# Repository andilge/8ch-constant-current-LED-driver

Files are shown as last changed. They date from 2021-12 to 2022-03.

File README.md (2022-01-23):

# 8 channel LED constant current driver
Constant current driver with esp32 MCU made for esphome

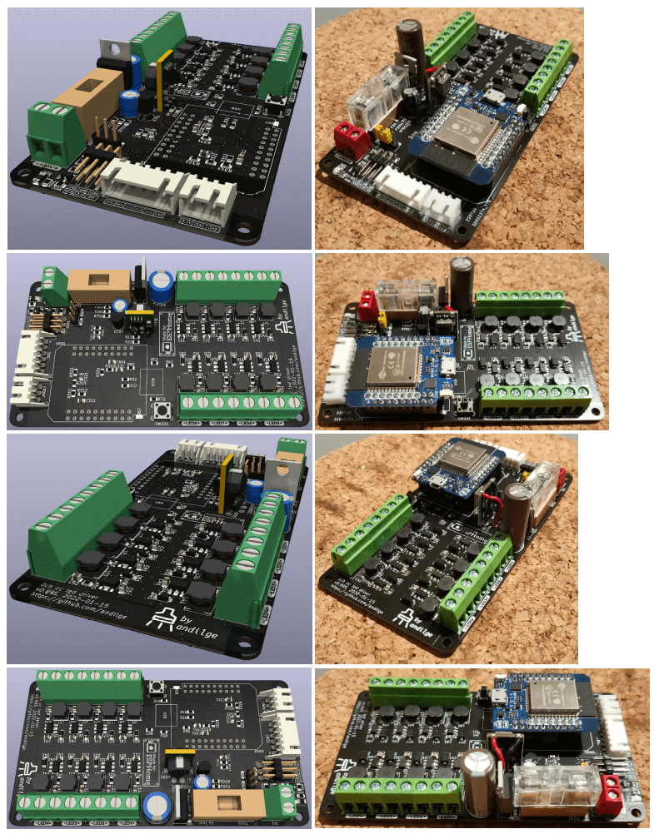
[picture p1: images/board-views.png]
The PCB


## Preamble
We are planning our new house. A seemingly endless process full of technical plans and proposed solutions. Among the proposals there are good ones, bad ones but also too expensive or immature ones.

In the field of automated lighting, the negatives outweigh the good in professional installations. I don’t need sinfully expensive lighting on closed and proprietary systems. Besides, I’ve been using Home Assistant for years and have learned to use ESPHome and want to build up on this.

With this starting position, the desire arose to do all the lighting in the new house myself and to rely on open source. Of course, in 2021 I will be using LED lights and I know that LEDs are best operated with constant current. After discussions with interested experts around the world, I arrived at the module LD24AJTA, which allows DC voltage and dimming with pwm at the input and offers a suitable constant current at the output.

Sweet, I can do nice pwm easily with an ESP32, the first prototype board was soon built up with it. If only all this could be done even faster and easier, without breadboard and soldering connections individually… you know what came next: I built up my own board with the essentials of the module LD24AJTA and an ESP32 on it.

## Where to find things
The board revisions are accessible in the folder "revisions". Check CHANGELOG.md for detailed revision history.

An example esphome yaml file is located in the folder "esphome".

## Controller add-on
Check out [Rotary encoder with a 10 WS2811 F5 LEDs segmented ring on a translucent white blinde plate](https://github.com/andilge/EC11-encoder-with-WS2811-ring "Rotary encoder with a 10 WS2811 F5 LEDs segmented ring on a translucent white blinde plate") as controller add-on for dimming and toggling the lights.

## Where to go
I know some additional information is needed to get going. I'm planning to build up a wiki here with a step by step procedure, but I got no time to roll this off swiftly :-(

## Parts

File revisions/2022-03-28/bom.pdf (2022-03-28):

## Board

Quantity | References | Value | Purchase
8 | C11, C21, C31, C41, C51, C61, C71, C81 | 10uF 50V
8 | C12, C22, C32, C42, C52, C62, C72, C82 | 1uF 50V
3 | C101, C311, C321 | 10nF 25V
1 | C102 | 680uF 50V
1 | C201 | 470uF 10V
3 | C331, C411, C601 | 100nF 50V
8 | D11, D21, D31, D41, D51, D61, D71, D81 | MBR0560
1 | D101 | BZT52C10
1 | D201 | Power LED
1 | F101 | Holder 5.2x20mm
1 | F101 | 4A fast blowing
1 | F201 | 1.1A resettable
1 | F202 | 0.5A resettable | lcsc.com (https://lcsc.com/product-detail/Resettable-Fuses_Brightking-Elec-TAIWAN-SMD0805B050TF_C269104.html)
| IN1, LED1, LED2, LED3, LED4, LED5, LED6,
1 | J301 | JST S6B-XH-A 6in | aliexpress.com
9 | | Screw_Terminal_01x02
1 | J401 | JST S3B-XH-A 3pin
1 | J501 | Pin Header 2x3 horizontal
1 | J801 | Pin Header 1x3 vertical
1 | J801
8 | L11, L21, L31, L41, L51, L61, L71, L81 | 100uH, GLE GCNR6045
1 | Q101 | BR50P06
1 | Q801 | BSS138
8 | *R11, R21, R31, R41, R51, R61, R71, R81 | 0.3Ω +-1%
8 | R12, R22, R32, R42, R52, R62, R72, R82 | 1kΩ
1 | R101 | 82kΩ
1 | R201 | 3.9kΩ
6 | R311, R312, R321, R322 | 10kΩ
2 | R331, R421 | 39kΩ
2 | R332, R422
1 | R701 | 4.7kΩ
1 | R801, R802 | 33Ω
1 | R803 | 33Ω
1 | R804 | 220Ω
1 | SW331 | SW_Push
8 | U11, U21, U31, U41, U51, U61, U71, U81 | PT4115
1 | U201 | step down 5V 3A
1 | U601 | ESP32 mini (CP2104!)
1 | U701 | DS18B20

* Note for R11 – R81

I recommend using +-1% tolerance for constant Iled values over the different channels
With 0.3Ω, it’s 0.1 / 0.3 = 333mA

Smallest recommended resistor is 0.22Ω which will end up in Iled max per channel slightly above 450mA lcsc.com (https://www.lcsc.com/product-detail/Multilayer-Ceramic-Capacitors-MLCC-SMD-SMT_Murata-Electronics-GRM21BR61H106KE43L_C440198.html)
lcsc.com (https://www.lcsc.com/product-detail/Multilayer-Ceramic-Capacitors-MLCC-SMD-SMT_CCTC-TCC0805X7R105M500FT_C376929.html)
lcsc.com (https://www.lcsc.com/product-detail/Multilayer-Ceramic-Capacitors-MLCC-SMD-SMT_Samsung-Electro-Mechanics-CL21B103KAANNNC_C2688117.html)
aliexpress.com
aliexpress.com (https://www.aliexpress.com/item/1005002375358357.html)
lcsc.com (https://lcsc.com/product-detail/Multilayer-Ceramic-Capacitors-MLCC-SMD-SMT_CCTC-TCC0805X7R104K500DT_C282732.html)
lcsc.com (https://www.lcsc.com/product-detail/Schottky-Barrier-Diodes-SBD_Changjiang-Electronics-Tech-CJ-MBR0560_C77338.html)
lcsc.com (https://www.lcsc.com/product-detail/Zener-Diodes_BORN-BZT52C10_C511887.html)
lcsc.com (https://lcsc.com/product-detail/Light-Emitting-Diodes-LED_Orient-ORH-R37A_C400035.html)
lcsc.com (https://www.lcsc.com/product-detail/Fuse-Holders_Xucheng-Elec-C58066_C58066.html)
lcsc.com (https://www.lcsc.com/product-detail/Fuses_Littelfuse-0217004-MXP_C142737.html)
lcsc.com (https://lcsc.com/product-detail/Resettable-Fuses_BHFUSE-BSMD0805-125-6V_C883114.html)
LED7, LED8 | lcsc.com (https://www.lcsc.com/product-detail/Screw-terminal_HIWA-PA001-2P_C128027.html)
| aliexpress.com (https://www.aliexpress.com/item/1005002111262882.html)
| lcsc.com (https://lcsc.com/product-detail/Pin-Headers_BOOMELE-Boom-Precision-Elec-C3410_C3410.html)
| lcsc.com (https://www.lcsc.com/product-detail/Pin-Headers_GEPU-GP26-2520WV-3P_C2681738.html)
Pin Header jumper, long green cap | aliexpress.com (https://www.aliexpress.com/item/1005001568280063.html)
| lcsc.com (https://www.lcsc.com/product-detail/Power-Inductors_GLE-GCNR6045-101MC_C439379.html)
| lcsc.com (https://www.lcsc.com/product-detail/MOSFETs_Foshan-Blue-Rocket-Elec-BR50P06_C358396.html)
| lcsc.com (https://lcsc.com/product-detail/MOSFETs_Yangzhou-Yangjie-Elec-Tech-BSS138_C400505.html)
| lcsc.com (https://lcsc.com/product-detail/Chip-Resistor-Surface-Mount_UNI-ROYAL-Uniroyal-Elec-0805W8F300LT5E_C247157.html)
| lcsc.com (https://www.lcsc.com/product-detail/Chip-Resistor-Surface-Mount_YAGEO-RC0805JR-071KL_C100046.html)
| lcsc.com (https://www.lcsc.com/product-detail/Chip-Resistor-Surface-Mount_YAGEO-AC0805JR-0782KL_C229256.html)
| lcsc.com (https://lcsc.com/product-detail/Chip-Resistor-Surface-Mount_UNI-ROYAL-Uniroyal-Elec-0805W8J0392T5E_C26021.html)
| lcsc.com (https://lcsc.com/product-detail/Chip-Resistor-Surface-Mount_FH-Guangdong-Fenghua-Advanced-Tech-RS-05K103JT_C115295.html)
| lcsc.com (https://lcsc.com/product-detail/Chip-Resistor-Surface-Mount_FH-Guangdong-Fenghua-Advanced-Tech-RS-05K393JT_C294712.html)
6.8kΩ | lcsc.com (https://lcsc.com/product-detail/Chip-Resistor-Surface-Mount_UNI-ROYAL-Uniroyal-Elec-0805W8J0682T5E_C26026.html)
| lcsc.com (https://lcsc.com/product-detail/Chip-Resistor-Surface-Mount_YAGEO-AC0805JR-074K7L_C229219.html)
| lcsc.com
| lcsc.com (https://lcsc.com/product-detail/Chip-Resistor-Surface-Mount_UNI-ROYAL-Uniroyal-Elec-0805W8J0330T5E_C25307.html)
| lcsc.com (https://lcsc.com/product-detail/Chip-Resistor-Surface-Mount_UNI-ROYAL-Uniroyal-Elec-0805W8J0221T5E_C25294.html)
| lcsc.com (https://lcsc.com/product-detail/Tactile-Switches_C-K-PTS645SL43-2LFS_C221874.html)
| lcsc.com (https://www.lcsc.com/product-detail/LED-Drivers_PowTech-CR-PowTech-Shanghai-PT4115B89E_C84512.html)
| aliexpress.com (https://www.aliexpress.com/item/1005003332040548.html)
| aliexpress.com (https://www.aliexpress.com/item/33043305592.html)
| lcsc.com (https://www.lcsc.com/product-detail/Temperature-Sensors_UMW-Youtai-Semiconductor-Co-Ltd-DS18B20_C376006.html)

The board can handle up to 500mA per channel. Changing the resistor has impact on Iled max which is calculated 0.1 / R.

You can throttle the power in esphome yaml code to meet your light's characteristic

## Installation

### Materials

Quantity | Reference | Value | Purchase
1 | Power supply | 24V/100W
1 | Enclosure box | 150x100x50mm
4 | M3x5 screw | M3x6
4 | M3 washer | M3x6x0.8
9 | DC sockets | DC-022B
9 | DC plugs | DC-022B
100m | DC cable | 20AWG
1 | | EC11
1 | Encoder knob | Marshall white
1 | Blank cover panel
1 | Motion detection sensor | AM312

### Tools

Quantity | Reference | Value | Purchase
1 | Crimping plier JST XH | SN-2549
1 | 3 ceramic tweezers | aliexpress.com (https://www.aliexpress.com/item/32872002684.html)
| Ferrules + Terminal
5m | Transparent heat shrink tube 3:1 | aliexpress.com (https://www.aliexpress.com/item/32707478629.html)
| SMD soldering heating
1 | 6" diagonal wire cutter nipper | aliexpress.com (https://www.aliexpress.com/item/1005003653231158.html)
| WAGO connectors combo
100g | Solder wire 0.6mm | aliexpress.com (https://www.aliexpress.com/item/1005002788585134.html)
1 | HSC8 6-6
1 | MECHANIC ET-10

1

1 | Soldering paste 138°C
1 | Extra Flux | | aliexpress.com (https://www.aliexpress.com/item/1005002680913932.html)
| Desoldering wick 2mm x
1 | Multimeter | ZT301 | aliexpress.com (https://www.aliexpress.com/item/32887493467.html)

1x10

aliexpress.com (https://www.aliexpress.com/item/4000834576979.html)
aliexpress.com (https://www.aliexpress.com/item/1005001861093267.html)
aliexpress.com (https://www.aliexpress.com/item/1005002306042593.html)
aliexpress.com (https://www.aliexpress.com/item/1005002439751580.html)
aliexpress.com (https://www.aliexpress.com/item/32923781995.html)
aliexpress.com (https://www.aliexpress.com/item/32897664061.html)
aliexpress.com (https://www.aliexpress.com/item/1005003474533191.html)
Rotary encoder 15mm
plum handle | aliexpress.com (https://www.aliexpress.com/item/1005002048077280.html)
| aliexpress.com (https://www.aliexpress.com/item/1005002362022710.html)
| aliexpress.com (https://www.aliexpress.com/item/32884601740.html)
| aliexpress.com (https://www.aliexpress.com/item/32988314171.html)

aliexpress.com (https://www.aliexpress.com/item/4000331316447.html)

Crimping Plier | aliexpress.com (https://www.aliexpress.com/item/32831768783.html?)
plate | aliexpress.com (https://www.aliexpress.com/item/1005001705260291.html)
kit | aliexpress.com (https://www.aliexpress.com/item/32371475690.html)
| aliexpress.com (https://www.aliexpress.com/item/1005002799325191.html)
1.5m | aliexpress.com (https://www.aliexpress.com/item/32931554391.html)

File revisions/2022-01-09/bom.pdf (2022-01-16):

## Board

Quantity | References | Value | Purchase
11 | | 100nF 50V
8 | C12, C22, C32, C42, C52, C62, C72, C82 | 1uF 50V
3 | C101, C311, C321 | 10nF 25V
1 | C102 | 470uF 50V
1 | C201 | 220uF 10V | lcsc.com (https://lcsc.com/product-detail/Aluminum-Electrolytic-Capacitors-Leaded_Capxon-International-Elec-KF221M010E070A_C59330.html)
| C331, C421, C601 | 100nF 50V
8 | D11, D21, D31, D41, D51, D61, D71, D81 | MBR0560 | lcsc.com (https://www.lcsc.com/product-detail/Schottky-Barrier-Diodes-SBD_Changjiang-Electronics-Tech-CJ-MBR0560_C77338.html)
1 | D101 | BZT52C10
1 | D201 | Pow LED
1 | F101 | Holder 5.2x20mm
1 | F101 | 4A fast blowing
1 | F201 | 1A resettable
9 | | Screw_Terminal_01x02
1 | J301 | S4B-XH-A
1 | J401 | S3B-XH-A
1 | J501 | Conn_02x04_Male
8 | L11, L21, L31, L41, L51, L61, L71, L81 | 100uH, GLE GCNR6045
1 | Q101 | BR50P06
8 | *R11, R21, R31, R41, R51, R61, R71, R81 | 0.3Ω +-1%
8 | R12, R22, R32, R42, R52, R62, R72, R82 | 1kΩ
1 | R101 | 82kΩ
1 | R201 | 3.9kΩ
4 | R311, R312, R321, R322 | 10kΩ
2 | R331, R421 | 39kΩ
2 | R332, R422
1 | R701 | 4.7kΩ
8 | U11, U21, U31, U41, U51, U61, U71, U81 | PT4115
1 | U201 | step down 5V 1A
1 | U601 | ESP32 mini (CP2104!)
1 | U701 | DS18B20

* Note for R11 – R81

I recommend using +-1% tolerance for constant Iled values over the different channels
With 0.3Ω, it’s 0.1 / 0.3 = 333mA

Smallest recommended resistor is 0.22Ω which will end up in Iled max per channel slightly above 450mA

C11, C21, C31, C41, C51, C61, C71, C81, C331, C421,
C601 | lcsc.com (https://www.lcsc.com/product-detail/Multilayer-Ceramic-Capacitors-MLCC-SMD-SMT_Murata-Electronics-GRM21BR61H106KE43L_C440198.html)
| lcsc.com (https://www.lcsc.com/product-detail/Multilayer-Ceramic-Capacitors-MLCC-SMD-SMT_CCTC-TCC0805X7R105M500FT_C376929.html)
| lcsc.com (https://www.lcsc.com/product-detail/Multilayer-Ceramic-Capacitors-MLCC-SMD-SMT_Samsung-Electro-Mechanics-CL21B103KAANNNC_C2688117.html)
| lcsc.com (https://www.lcsc.com/product-detail/Aluminum-Electrolytic-Capacitors-Leaded_KNSCHA-01EC4236_C2760863.html)
| lcsc.com (https://lcsc.com/product-detail/Multilayer-Ceramic-Capacitors-MLCC-SMD-SMT_CCTC-TCC0805X7R104K500DT_C282732.html)
| lcsc.com (https://www.lcsc.com/product-detail/Zener-Diodes_Shandong-Jingdao-Microelectronics-BZT52C10_C353564.html)
| lcsc.com (https://lcsc.com/product-detail/Light-Emitting-Diodes-LED_Orient-ORH-R37A_C400035.html)
| lcsc.com (https://www.lcsc.com/product-detail/Fuse-Holders_Xucheng-Elec-C58066_C58066.html)
| lcsc.com (https://www.lcsc.com/product-detail/Fuses_Littelfuse-0217004-MXP_C142737.html)
| lcsc.com (https://lcsc.com/product-detail/Resettable-Fuses_BHFUSE-BSMD0805-100-12V_C910823.html)
IN1, LED1, LED2, LED3, LED4, LED5, LED6, LED7,
LED8 | lcsc.com (https://www.lcsc.com/product-detail/Screw-terminal_HIWA-PA001-2P_C128027.html)
| lcsc.com (https://lcsc.com/product-detail/Wire-To-Board-Wire-To-Wire-Connector_BOOMELE-Boom-Precision-Elec-XH-4AW_C21273.html)
| lcsc.com (https://lcsc.com/product-detail/Wire-To-Board-Wire-To-Wire-Connector_BOOMELE-Boom-Precision-Elec-XH-3AW_C18428.html)
| lcsc.com (https://lcsc.com/product-detail/Pin-Headers_BOOMELE-Boom-Precision-Elec-C3410_C3410.html)
| lcsc.com (https://www.lcsc.com/product-detail/Power-Inductors_GLE-GCNR6045-101MC_C439379.html)
| lcsc.com (https://www.lcsc.com/product-detail/MOSFETs_Foshan-Blue-Rocket-Elec-BR50P06_C358396.html)
| lcsc.com (https://lcsc.com/product-detail/Chip-Resistor-Surface-Mount_UNI-ROYAL-Uniroyal-Elec-0805W8F300LT5E_C247157.html)
| lcsc.com (https://www.lcsc.com/product-detail/Chip-Resistor-Surface-Mount_YAGEO-RC0805JR-071KL_C100046.html)
| lcsc.com (https://www.lcsc.com/product-detail/Chip-Resistor-Surface-Mount_YAGEO-AC0805JR-0782KL_C229256.html)
| lcsc.com (https://lcsc.com/product-detail/Chip-Resistor-Surface-Mount_UNI-ROYAL-Uniroyal-Elec-0805W8J0392T5E_C26021.html)
| lcsc.com (https://lcsc.com/product-detail/Chip-Resistor-Surface-Mount_FH-Guangdong-Fenghua-Advanced-Tech-RS-05K103JT_C115295.html)
| lcsc.com (https://lcsc.com/product-detail/Chip-Resistor-Surface-Mount_FH-Guangdong-Fenghua-Advanced-Tech-RS-05K393JT_C294712.html)
6.8kΩ | lcsc.com (https://lcsc.com/product-detail/Chip-Resistor-Surface-Mount_UNI-ROYAL-Uniroyal-Elec-0805W8J0682T5E_C26026.html)
| lcsc.com (https://lcsc.com/product-detail/Chip-Resistor-Surface-Mount_YAGEO-AC0805JR-074K7L_C229219.html)
| lcsc.com (https://www.lcsc.com/product-detail/LED-Drivers_PowTech-CR-PowTech-Shanghai-PT4115B89E_C84512.html)
| aliexpress.com (https://www.aliexpress.com/item/1005001910573870.html)
| aliexpress.com (https://www.aliexpress.com/item/33043305592.html)
| lcsc.com (https://www.lcsc.com/product-detail/Temperature-Sensors_UMW-Youtai-Semiconductor-Co-Ltd-DS18B20_C376006.html)

The board can handle up to 500mA per channel. Changing the resistor has impact on Iled max which is calculated 0.1 / R.

You can throttle the power in esphome yaml code to meet your light's characteristic

## Installation

### Materials

Quantity | Reference | Value | Purchase
1 | Power supply | 24V/100W
1 | Enclosure box | 150x100x50mm
4 | M3x5 screw | M3x6
4 | M3 washer | M3x6x0.8
9 | DC sockets | DC-022B
9 | DC plugs | DC-022B
100m | DC cable | 20AWG
1 | Rotary encoder | EC11
1 | Encoder knob | Marshall white
1 | Blank cover panel
1 | Motion detection sensor | AM312

### Tools

Quantity | Reference | Value | Purchase
1 | Crimping plier JST XH | SN-2549

aliexpress.com (https://www.aliexpress.com/item/4000834576979.html)
aliexpress.com (https://www.aliexpress.com/item/1005001861093267.html)
aliexpress.com (https://www.aliexpress.com/item/1005002306042593.html)
aliexpress.com (https://www.aliexpress.com/item/1005002439751580.html)
aliexpress.com (https://www.aliexpress.com/item/32923781995.html)
aliexpress.com (https://www.aliexpress.com/item/32897664061.html)
aliexpress.com (https://www.aliexpress.com/item/1005003474533191.html)
aliexpress.com (https://www.aliexpress.com/item/1005002048077280.html)
aliexpress.com (https://www.aliexpress.com/item/1005002362022710.html)
aliexpress.com (https://www.aliexpress.com/item/32884601740.html)
aliexpress.com (https://www.aliexpress.com/item/32988314171.html)

aliexpress.com (https://www.aliexpress.com/item/4000331316447.html)

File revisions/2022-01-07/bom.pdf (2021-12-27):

## Board

Quantity | References | Value | Purchase
11 | | 100nF 50V
8 | C12, C22, C32, C42, C52, C62, C72, C82 | 1uF 50V
3 | C101, C311, C321 | 10nF 25V
1 | C102 | 470uF 50V
1 | C201 | 220uF 10V
8 | D11, D21, D31, D41, D51, D61, D71, D81 | MBR0560
1 | D101 | BZT52C10
1 | D201 | Pow LED
1 | F101 | Holder 5.2x20mm
1 | F101 | 4A fast blowing
1 | F201 | 1A resettable | lcsc.com (https://lcsc.com/product-detail/Resettable-Fuses_BHFUSE-BSMD0805-100-12V_C910823.html)
| IN1, LED1, LED2, LED3, LED4, LED5, LED6, LED7,
1 | J301 | S4B-XH-A | lcsc.com (https://lcsc.com/product-detail/Wire-To-Board-Wire-To-Wire-Connector_JST-Sales-America-S4B-XH-A-LF-SN_C157925.html)
9 | | Screw_Terminal_01x02
1 | J401 | S3B-XH-A
1 | J501 | Conn_02x04_Male
8 | L11, L21, L31, L41, L51, L61, L71, L81 | 100uH, GLE GCNR6045
1 | Q101 | BR50P06
8 | *R11, R21, R31, R41, R51, R61, R71, R81 | 0.36Ω +-1%
1 | R101 | 82kΩ
1 | R201 | 3.9kΩ
4 | R311, R312, R321, R322 | 10kΩ
2 | R332, R422
2 | R331, R421 | 39kΩ
1 | R701 | 4.7kΩ
8 | U11, U21, U31, U41, U51, U61, U71, U81 | PT4115
1 | U201 | step down 5V 1A
1 | U601 | ESP32 mini (CP2104!)
1 | U701 | DS18B20

* Note for R11 – R81

With 0.36Ω, it’s 0.1 / 0.36 = 278mA (measured 290mA)
I recommend using +-1% tolerance for constant Iled values over the different channels
Smallest recommended resistor is 0.22Ω which will end up in Iled max per channel little more than 450mA

C11, C21, C31, C41, C51, C61, C71, C81, C331, C421,
C601 | lcsc.com (https://lcsc.com/product-detail/Multilayer-Ceramic-Capacitors-MLCC-SMD-SMT_CCTC-TCC0805X7R104K500DT_C282732.html)
| lcsc.com (https://www.lcsc.com/product-detail/Multilayer-Ceramic-Capacitors-MLCC-SMD-SMT_CCTC-TCC0805X7R105M500FT_C376929.html)
| lcsc.com (https://lcsc.com/product-detail/Multilayer-Ceramic-Capacitors-MLCC-SMD-SMT_Samsung-Electro-Mechanics-CL21B103KAANNNC_C2688117.html)
| lcsc.com (https://www.lcsc.com/product-detail/Aluminum-Electrolytic-Capacitors-Leaded_KNSCHA-01EC4236_C2760863.html)
| lcsc.com (https://www.lcsc.com/product-detail/Aluminum-Electrolytic-Capacitors-Leaded_Capxon-International-Elec-KF221M010E070A_C59330.html)
| lcsc.com (https://www.lcsc.com/product-detail/Schottky-Barrier-Diodes-SBD_Changjiang-Electronics-Tech-CJ-MBR0560_C77338.html)
| lcsc.com (https://www.lcsc.com/product-detail/Zener-Diodes_GOODWORK-BZT52C10_C2903914.html)
| lcsc.com (https://www.lcsc.com/product-detail/Light-Emitting-Diodes-LED_Lite-On-LTST-C150KFKT_C284937.html)
| lcsc.com (https://www.lcsc.com/product-detail/Fuse-Holders_Xucheng-Elec-C58066_C58066.html)
| lcsc.com (https://www.lcsc.com/product-detail/Fuses_Walter-Elec-FSD5A250V_C357863.html)
LED8 | lcsc.com (https://lcsc.com/product-detail/Screw-terminal_HIWA-PA001-2P_C128027.html)
| lcsc.com (https://lcsc.com/product-detail/Wire-To-Board-Wire-To-Wire-Connector_JST-Sales-America-S3B-XH-A-LF-SN_C157928.html)
| lcsc.com (https://lcsc.com/product-detail/Pin-Headers_BOOMELE-Boom-Precision-Elec-C3410_C3410.html)
| lcsc.com (https://lcsc.com/product-detail/Power-Inductors_GLE-GCNR6045-101MC_C439379.html)
| lcsc.com (https://www.lcsc.com/product-detail/MOSFETs_Foshan-Blue-Rocket-Elec-BR50P06_C358396.html)
| lcsc.com (https://lcsc.com/product-detail/Chip-Resistor-Surface-Mount_Milliohm-HoLTT0805-1-8W-360mR-1_C2904550.html)
| lcsc.com (https://www.lcsc.com/product-detail/Chip-Resistor-Surface-Mount_FH-Guangdong-Fenghua-Advanced-Tech-RS-05K823JT_C294742.html)
| lcsc.com (https://www.lcsc.com/product-detail/Chip-Resistor-Surface-Mount_UNI-ROYAL-Uniroyal-Elec-0805W8J0332T5E_C26020.html)
| lcsc.com (https://lcsc.com/product-detail/Chip-Resistor-Surface-Mount_FH-Guangdong-Fenghua-Advanced-Tech-RS-05K103JT_C115295.html)
6.8kΩ | lcsc.com (https://lcsc.com/product-detail/Pin-Headers_BOOMELE-Boom-Precision-Elec-C3410_C3410.html)
| lcsc.com (https://lcsc.com/product-detail/Chip-Resistor-Surface-Mount_FH-Guangdong-Fenghua-Advanced-Tech-RS-05K393JT_C294712.html)
| lcsc.com (https://www.lcsc.com/product-detail/Chip-Resistor-Surface-Mount_FOJAN-FRC0805J472-TS_C2907326.html)
| lcsc.com (https://www.lcsc.com/product-detail/LED-Drivers_PowTech-CR-PowTech-Shanghai-PT4115B89E_C84512.html)
| aliexpress.com (https://www.aliexpress.com/item/4000549890103.html)
| aliexpress.com (https://www.aliexpress.com/item/32858054775.html)
| lcsc.com (https://www.lcsc.com/product-detail/Temperature-Sensors_UMW-Youtai-Semiconductor-Co-Ltd-DS18B20_C376006.html)

The board can handle up to 500mA per channel. Changing the resistor has impact on Iled max which is calculated 0.1 / R.

## Installation

Quantity | Reference | Value | Purchase
1 | Power supply | 24V/100W
1 | Enclosure box | 150x100x50mm
4 | M3x5 screw | M3x6
4 | M3 washer | M3x6x0.8
9 | DC sockets | DC-022B
9 | DC plugs | DC-022B
100m | DC cable | 20AWG
1 | Rotary encoder | EC11
1 | Blank cover panel
1 | Encoder knob
1 | Motion detection sensor | AM312
1 | Crimping plier JST XH | SN-2549

aliexpress.com (https://www.aliexpress.com/item/4000834576979.html)
aliexpress.com (https://www.aliexpress.com/item/1005001861093267.html)
aliexpress.com (https://www.aliexpress.com/item/1005002306042593.html)
aliexpress.com (https://www.aliexpress.com/item/1005002439751580.html)
aliexpress.com (https://www.aliexpress.com/item/32923781995.html)
aliexpress.com (https://www.aliexpress.com/item/32897664061.html)
aliexpress.com (https://www.aliexpress.com/item/1005003474533191.html)
aliexpress.com (https://www.aliexpress.com/item/1005002048077280.html)
aliexpress.com (https://www.aliexpress.com/item/32884601740.html)
aliexpress.com (https://www.aliexpress.com/item/1005002362022710.html)
aliexpress.com (https://www.aliexpress.com/item/32988314171.html)
aliexpress.com (https://www.aliexpress.com/item/4000331316447.html)

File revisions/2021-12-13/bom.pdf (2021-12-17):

## Board

Quantity | References | Value | Purchase
9 | C11, C21, C31, C41, C51, C61, C71, C81, C201 | 100nF 50V
8 | C12, C22, C32, C42, C52, C62, C72, C82 | 1uF 50V
1 | C100 | 10nF 25V
1 | C101 | 470uF 50V
1 | C200 | 220uF 10V
8 | *R1, R2, R3, R4, R5, R6, R7, R8 | 0R36 +-1%
1 | R20 | 4k7
1 | R100 | 82k
1 | R200 | 3k3 | lcsc.com (https://www.lcsc.com/product-detail/Chip-Resistor-Surface-Mount_UNI-ROYAL-Uniroyal-Elec-0805W8J0332T5E_C26020.html)
| | 100uH, GLE GCNR6045-
8 | D1, D2, D3, D4, D5, D6, D7, D8 | MBR0560 | lcsc.com (https://www.lcsc.com/product-detail/Schottky-Barrier-Diodes-SBD_Changjiang-Electronics-Tech-CJ-MBR0560_C77338.html)
8 | L1, L2, L3, L4, L5, L6, L7, L8
1 | D100 | BZT52C10
1 | D200 | Pow LED
8 | U1, U2, U3, U4, U5, U6, U7, U8 | PT4115
1 | U10 | ESP32 mini (CP2104 drive)
1 | U20 | DS18B20
1 | U200 | step down 5V 1A
1 | F100 | Holder 5.2x20mm
| | 5A fast blowing
1 | F200 | 1A
9 | | Screw_Terminal_01x02
1 | Q100 | BR50P06
1 | J110 | Conn_01x06_Male
1 | J120 | Conn_01x03_Male
1 | J130 | Conn_01x04_Male

* Note for R1 – R8

With 0.36Ω, it’s 0.1 / 0.36 = 278mA (measured 290mA)
I recommend using +-1% tolerance for constant Iled values over the different channels
Smallest recommended resistor is 0.22Ω which will end up in Iled max per channel little more than 450mA lcsc.com (https://www.lcsc.com/product-detail/Multilayer-Ceramic-Capacitors-MLCC-SMD-SMT_CCTC-TCC0805X7R104K500DT_C282732.html)
lcsc.com (https://www.lcsc.com/product-detail/Multilayer-Ceramic-Capacitors-MLCC-SMD-SMT_CCTC-TCC0805X7R105M500FT_C376929.html)
lcsc.com (https://www.lcsc.com/product-detail/Multilayer-Ceramic-Capacitors-MLCC-SMD-SMT_YAGEO-CC0805KRX7R8BB103_C519911.html)
lcsc.com (https://www.lcsc.com/product-detail/Aluminum-Electrolytic-Capacitors-Leaded_KNSCHA-01EC4236_C2760863.html)
lcsc.com (https://www.lcsc.com/product-detail/Aluminum-Electrolytic-Capacitors-Leaded_Capxon-International-Elec-KF221M010E070A_C59330.html)
lcsc.com (https://www.lcsc.com/product-detail/Chip-Resistor-Surface-Mount_UNI-ROYAL-Uniroyal-Elec-0805W8F360LT5E_C35793.html)
lcsc.com (https://www.lcsc.com/product-detail/Chip-Resistor-Surface-Mount_FOJAN-FRC0805J472-TS_C2907326.html)
lcsc.com (https://www.lcsc.com/product-detail/Chip-Resistor-Surface-Mount_FH-Guangdong-Fenghua-Advanced-Tech-RS-05K823JT_C294742.html)
101MC | lcsc.com (https://www.lcsc.com/product-detail/Power-Inductors_GLE-GCNR6045-101MC_C439379.html)
| lcsc.com (https://www.lcsc.com/product-detail/Zener-Diodes_GOODWORK-BZT52C10_C2903914.html)
| lcsc.com (https://www.lcsc.com/product-detail/Light-Emitting-Diodes-LED_Lite-On-LTST-C150KFKT_C284937.html)
| lcsc.com (https://www.lcsc.com/product-detail/LED-Drivers_PowTech-CR-PowTech-Shanghai-PT4115B89E_C84512.html)
| aliexpress.com (https://www.aliexpress.com/item/33043305592.html)
| lcsc.com (https://www.lcsc.com/product-detail/Temperature-Sensors_UMW-Youtai-Semiconductor-Co-Ltd-DS18B20_C376006.html)
| aliexpress.com (https://www.aliexpress.com/item/1005001910573870.html)
| lcsc.com (https://www.lcsc.com/product-detail/Fuse-Holders_Xucheng-Elec-C58066_C58066.html)
| lcsc.com (https://www.lcsc.com/product-detail/Fuses_Walter-Elec-FSD5A250V_C357863.html)
| lcsc.com (https://www.lcsc.com/product-detail/Resettable-Fuses_Jinrui-Electronic-Materials-Co-JK-SMD0805-100-6V_C2830233.html)
IN1, LED1, LED2, LED3, LED4, LED5, LED6, LED7,
LED8 | lcsc.com (https://www.lcsc.com/product-detail/Screw-terminal_Cixi-Kefa-Elec-KF301-5-0-2P_C474881.html)
| lcsc.com (https://www.lcsc.com/product-detail/MOSFETs_Foshan-Blue-Rocket-Elec-BR50P06_C358396.html)
| aliexpress.com (https://www.aliexpress.com/item/33043163402.html)
| aliexpress.com (https://www.aliexpress.com/item/4000029752340.html)
| aliexpress.com (https://www.aliexpress.com/item/4000029721517.html)

The board can handle up to 500mA per channel. Changing the resistor has impact on Iled max which is calculated 0.1 / R.

## Installation

Quantity | Reference | Value | Purchase
1 | Power supply | 24V/100W
1 | Enclosure box | 150x100x50mm
4 | M3x5 screw | M3x6
4 | M3 washer | M3x6x0.8
9 | DC sockets | DC-022B
9 | DC plugs | DC-022B
100m | DC cable | 20AWG
1 | Rotary encoder | EC11
1 | Blank cover panel
1 | Encoder knob
1 | Motion detection sensor | AM312
1 | Crimping plier JST XH | SN-2549

aliexpress.com (https://www.aliexpress.com/item/4000834576979.html)
aliexpress.com (https://www.aliexpress.com/item/1005001861093267.html)
aliexpress.com (https://www.aliexpress.com/item/1005002306042593.html)
aliexpress.com (https://www.aliexpress.com/item/1005002439751580.html)
aliexpress.com (https://www.aliexpress.com/item/32923781995.html)
aliexpress.com (https://www.aliexpress.com/item/32897664061.html)
aliexpress.com (https://www.aliexpress.com/item/1005003474533191.html)
aliexpress.com (https://www.aliexpress.com/item/1005002048077280.html)
aliexpress.com (https://www.aliexpress.com/item/32884601740.html)
aliexpress.com (https://www.aliexpress.com/item/1005002362022710.html)
aliexpress.com (https://www.aliexpress.com/item/32988314171.html)
aliexpress.com (https://www.aliexpress.com/item/4000331316447.html)

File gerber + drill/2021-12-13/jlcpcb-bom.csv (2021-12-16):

Comment | Designator | Footprint | LCSC
10nF | C100 | Capacitor_SMD:C_0805_2012Metric | C2688117
470uF | C101 | Capacitor_THT:CP_Radial_D10.0mm_P5.00mm | C2760863
100nF | C10,C11,C21,C31,C41,C51,C61,C71,C81 | Capacitor_SMD:C_0805_2012Metric | C282732
1uF | C12,C22,C32,C42,C52,C62,C72,C82 | Capacitor_SMD:C_0805_2012Metric | C376929
220uF | C200 | Capacitor_THT:CP_Radial_D6.3mm_P2.50mm | C59330
BZT52C10 | D100 | Diode_SMD:D_SOD-323 | C353564
Pow LED | D200 | Diode_SMD:D_1206_3216Metric | C130716
MBR0560 | D1,D2,D3,D4,D5,D6,D7,D8 | Diode_SMD:D_SOD-123 | C77338
5A fast | F100 | Fuse:Fuseholder_Cylinder-5x20mm_Stelvio-Kontek_PTF78_Horizontal_Open | C58066
1A | F200 | Resistor_SMD:R_0805_2012Metric | C369152
Screw_Terminal_01x02 | IN1,LED1,LED2,LED3,LED4,LED5,LED6,LED7,LED8 | TerminalBlock_MetzConnect:TerminalBlock_MetzConnect_Type101_RT01602HBWC_1x02_P5.08mm_Horizontal | C474881
Conn_01x06_Male | J110 | Connector_PinHeader_2.54mm:PinHeader_2x03_P2.54mm_Horizontal | C492431
Conn_01x03_Male | J120 | Connector_JST:JST_EH_S3B-EH_1x03_P2.50mm_Horizontal | C144402
Conn_01x04_Male | J130 | Connector_JST:JST_EH_S4B-EH_1x04_P2.50mm_Horizontal | C144403
100uH | L1,L2,L3,L4,L5,L6,L7,L8 | Inductor_SMD:L_Bourns_SRN6045TA | C439379
BR50P06 | Q100 | Package_TO_SOT_THT:TO-220-3_Vertical | C358396
82k | R100 | Resistor_SMD:R_0805_2012Metric | C229256
4k7 | R20 | Resistor_SMD:R_0805_2012Metric | C229219
3k3 | R200 | Resistor_SMD:R_0805_2012Metric | C26020
0R36 | R1,R2,R3,R4,R5,R6,R7,R8 | Resistor_SMD:R_0805_2012Metric | C35793
PT4115 | U1,U2,U3,U4,U5,U6,U7,U8 | Package_TO_SOT_SMD:SOT-89-5 | C84512
DS18B20 | U20 | Package_TO_SOT_THT:TO-92_Inline | C376006

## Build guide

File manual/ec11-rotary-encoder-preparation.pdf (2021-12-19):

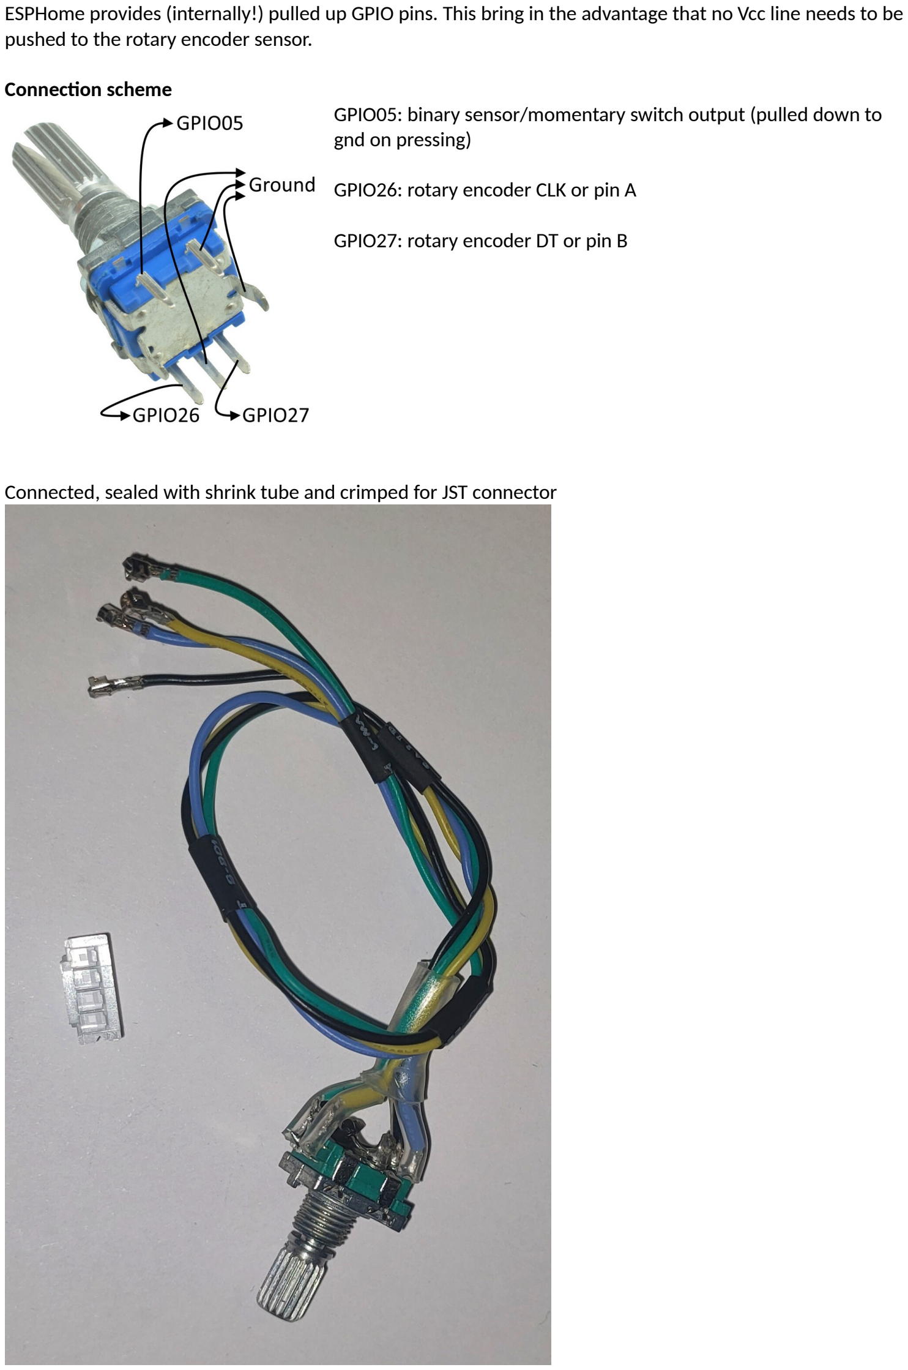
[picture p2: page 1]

ESPHome provides (internally!) pulled up GPIO pins. This bring in the advantage that no Vcc line needs to be pushed to the rotary encoder sensor.

Connection scheme
GPIO05: binary sensor/momentary switch output (pulled down to gnd on pressing)

GPIO26: rotary encoder CLK or pin A

GPIO27: rotary encoder DT or pin B

Connected, sealed with shrink tube and crimped for JST connector

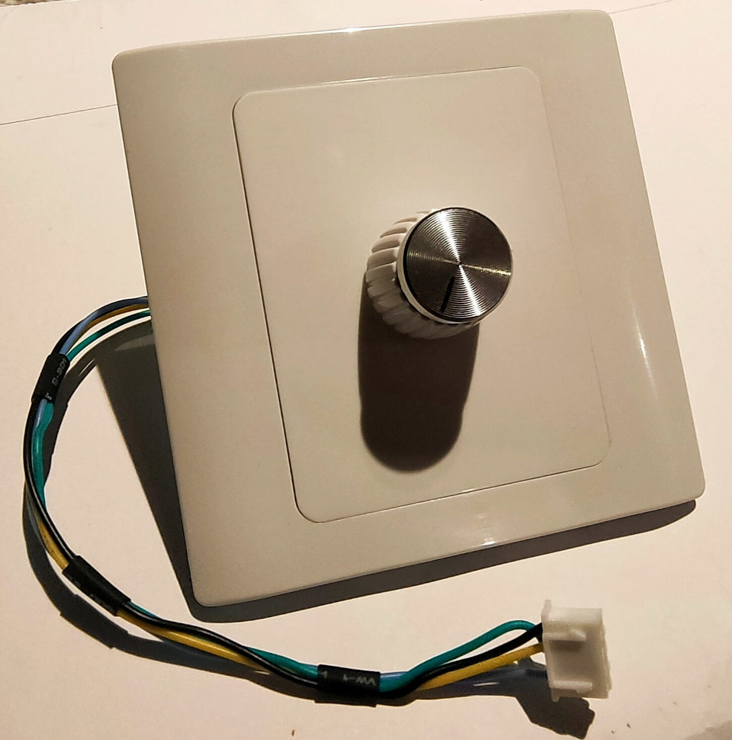
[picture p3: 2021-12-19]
manual/ec11-rotary-encoder-final.jpg

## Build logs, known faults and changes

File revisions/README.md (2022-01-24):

# Each folder stands for it's own revision showing the build date

## folder board-views
Here some preview pictures of the board. What you see is what you'll get in the end.

## folder jlcpcb-board-fabrication
### jlcpcb-gerber-drill-map.zip
The zip file is adapted to the manufacturers needs and contains it all. No need to unpack, it can be uploaded to the board manufacturer as it is. All tests with the board passed QC with 1oz copper layers.

### smt-bom.csv and smt-top-pos.csv
These 2 files can be used if you want jlcpcb.com to solder all SMD components on the board. Please upload smt-bom.csv as BOM, smt-top-pos.csv as CPL.
**ATTENTION**: All through hole components are *NOT* included in this BOM and the pre-assembly process. Please complete the board by manualy soldering them!

## folder pcbway-board-fabrication
### pcbway-gerber-drill-map.zip
The zip file is adapted to the manufacturers needs and contains it all. No need to unpack, it can be uploaded to the board manufacturer as it is. All tests with the board passed QC with 1oz copper layers.

## bom.pdf
This is the list with all parts and some installation material. *Download* the file and get access to real offers in the column "purchase" (suggestive).

## ibom.html
This is the interactive bill of materials which will help you placing the components on the board. It also shows more information about the components' footprint designators.

Here some [usage hints](https://github.com/openscopeproject/InteractiveHtmlBom/wiki/Usage#bom-page-mouse-actions).

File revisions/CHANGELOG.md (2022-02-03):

# Changelog

## [Unreleased]
### To be added
- Bigger 5V buck converter to serve additional power consumption of the addressbale LEDs
- Deep diving once again into tests with infrared thermal cam on the very last revision. Don't get me wrong, this has been done with positive results in earlier revisions and it's only been improved. Documentation and publication is lacking though
- Wiki and step by step guide. I know I'm lazy at documentation, just more fascinated in getting things up, running and QCed :-)
- Tests with all the external sensor/actor stuff with pir motion sensor and rotary encoder on 10 meter distant from board. Since the connectors have changed with v0.99 and debouncing/hum filter has dropped in with v0.991 I'll have to wait until these parts and the new board version are here first

## [0.996] - 2022-02-03
### Added
### Changed
- better zone handling around the mounting holes
- wider radius on many rounded corners for trackes, better track fillets
- better placement on some debouncing filter components, shortening tracks
- some minor cosmetics all around the board
### Deprecated
### Removed
### Fixed
### Security

## [0.995] - 2022-01-15
### Added
- Introducing a data bus for adressable LEDs on 6 pin JST XH connector going to encoder
- Simple level shifter 3.3V to 5V for data line
- Selectable data line attenuation 33Ω (short cable) or 253Ω (long cable) with pin header jumper
- Addtitional resettable fuse for LED power line
### Changed
- new buck converter delivering more power for the adressable LEDs on the controller
- new placment for power supply, debouncing filter and connector components
- rerouting all tracks on these components
### Deprecated
### Removed
### Fixed
### Security

## [0.994] - 2022-01-07
### Added
- Adding push button on the board (parallel to the one in the rotary encoder)
### Changed
- Fillet tracks for all tracks
- Minor routing improvments all over the board
### Deprecated
### Removed
### Fixed
- Eliminating some courtyard overlap errors by slightly changing component placements
- Adding decoupling resistors in PWM lines
### Security

## [0.993] - 2022-01-07
### Added
- Introducing fillet tracks (rounded corner in tracks)
### Changed
- Moving the light power components to the board's edge => larger power zone in the middle, lowering resistance
- Redoing all the zones, reconnecting some tracks
- Revamping the buzzard labels near the screw terminals
### Deprecated
### Removed
### Fixed
### Security

## [0.992] - 2022-01-05
### Added
- Introducing small buzzard labels near the screw terminals
- Introducing thermal reliefs on though hole and smd solder pads when in a zone
### Changed
- minor changes of placement of some vias, moving away from silk screens
### Deprecated
### Removed
### Fixed
### Security

## [0.99r2] - 2021-12-16
### Added
- introducing jlcpcb-smd-bom.csv BOM and jlcpcb-top-pos.csv CPL for the SMD assembly of the board by jlcpcb. **ATTENTION**: All through hole components are NOT included in this per-assembly process. Please complete the board by manually soldering them
### Changed
### Deprecated
### Removed
### Fixed
### Security

## [0.99] - 2021-12-13
### Added
### Changed
- using horizontal JST connectors near the board edge to enable connecting the pir sensor and rotary encoder easily thru the enclosure
- new placement for the esp32 giving space for the JST connectors near the board edge
- rerouting all tracks around the JST connectors and esp32
- minor improvments in the 5 Volt line, better componenent placement and track routing
### Deprecated
### Removed
### Fixed
### Security

## [0.98] - 2021-12-12
### Added
### Changed
- new power inductor Bourns SRN6045 for better availabilty (widley spread in different stocks).
- Alternative inductor is GLE GCNR6045 with same characteristics and dimensions
- spreading out ground area on front and back layer
- silkscreen near screw terminal connectors LED1 - LED4 rotated for better readability
- new graphics for board dimensions and mounting hole distances
### Deprecated
### Removed
### Fixed
### Security

## [0.97] - 2021-12-10
### Added
- introducing CHANGELOG.md with format based on [Keep a Changelog](https://keepachangelog.com)
### Changed
- optimizing vias
- small improvement on vcc tracks to led driver ic
- other minor enhancements and improvements
### Deprecated
### Removed
### Fixed
### Security

## [0.96] - 2021-12-07
### Added
### Changed
- better silkscreens at screw terminal connectors
- thicker and better tracks to the LED outputs
- other minor enhancements and improvements
### Deprecated
### Removed
### Fixed
### Security

## [0.95] - 2021-12-06
### Added
### Changed
- minor enhancements and improvements
### Deprecated
### Removed
### Fixed
### Security

## [0.95] - 2021-12-04
### Added
- [lcsc](https://lcsc.com/) part number in bom.pdf where possible, trying to scope on pre building the board. Not including (not available or too expensive, better get them from [aliexpress](https://aliexpress.com))
  - ESP32 mini
  - step down converter module 5V 1A
- first time usage of teardrops on round tht pads
- introducing the interactive bom (ibom.html) as help for component placement reference on board
### Changed
- joined the free to use GPIOs, 5 Volt fused and ground header pins in one horizontal connector
- using electrolyte capacitors with tht layout (formally smd) for better availability/prices and easier handling
- new smd power inductors for better availability/prices and a bit more space on the board
- new smd schotty power diodes for better availability/prices and a bit more space on the board
- smaller tracks for low power connections
- improved placement for led power components
- optimized led power track routing
### Deprecated
### Removed
- after some discussions with others about the external 5Volt in function and considering my personal usage case, the decision was taken to remove this functionality. The benefit is arguable and very low, the complexity rises, better keep it simple.
### Fixed
### Security

## [0.93] - 2021-11-25
### Added
- First trial with external 5V in to keep the MCU powered on even when the bigger power supply is powered off
- placing a small on broad double throw single pole switch to chose the matching MCU power source
- setting up silkscreen indications near the dtsp switch
- rerouting MCU power tracks
- renaming exposed GPIO silkscreens for external relay
### Changed
### Deprecated
### Removed
### Fixed
### Security

## [0.92] - 2021-11-16
### Added
### Changed
- minor enhancements and improvements
### Deprecated
### Removed
### Fixed
### Security

## [0.91] - 2021-11-12
### Added
### Changed
- minor enhancements and improvements
### Deprecated
### Removed
### Fixed
### Security

## [0.9] - 2021-11-11
### Added
### Changed
- focusing on installing the board in a pre made enclosure with mounting hole distances 105-55mm
- shrinking the board size
- setting up a 4th mounting hole on the board and placing all of them at the correct place
- adapting edge cuts with rounded corners to the matching size
- redoing **all component placement, all track routing and all silkscreens** from almost zero
- testing, measuring, checking heat dissipation with ir cam, rechecking power handling and long term tests once again
### Deprecated
### Removed
### Fixed
### Security

## [earlier revisions]
- basically doing some fundamental testing/measuring, choosing the matching components, shrinking the board to a compact size while improving it's power throughput
- achieving the official permission to use the "made for ESPHome"-Logo
- showing the project to specialists, getting their opinion and answering some questions
- measuring, burning parts, rebuilding, ordering prototype boards, soldering components, collecting information and throw the earlier prototype boards to trash moving on to the next prototype revision ... ~ 25 or more iterations like this
- this stage is not published in the changelog as it is a creative and chaotic process.

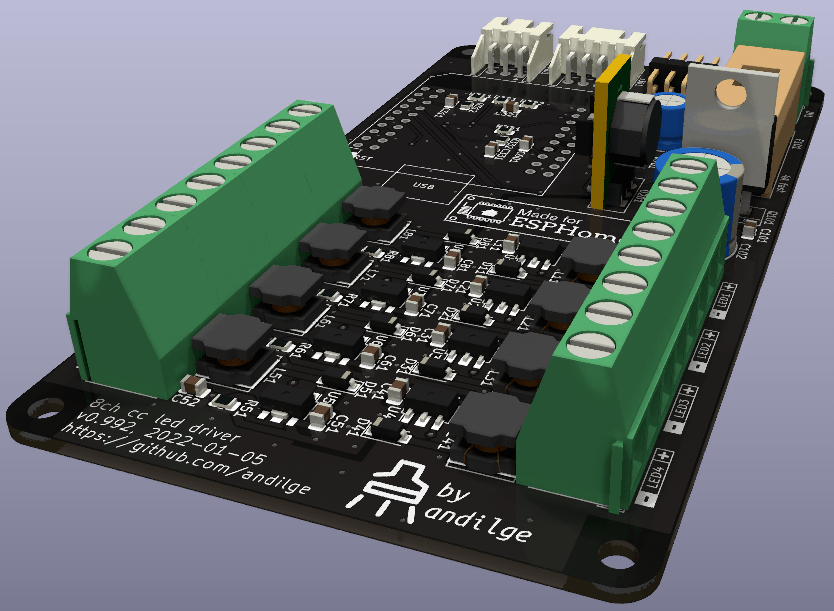
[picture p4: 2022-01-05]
revisions/2022-01-05/board-views/back.png

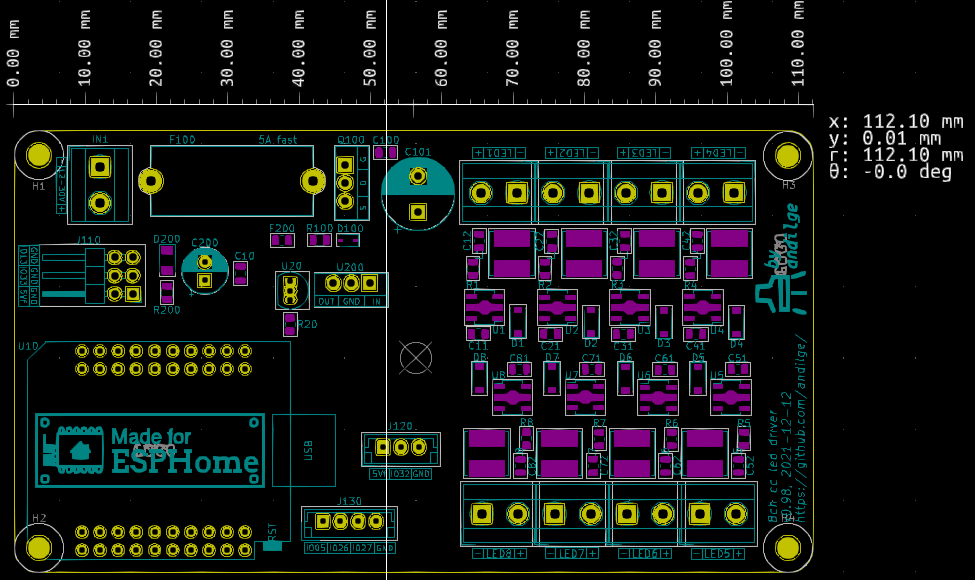
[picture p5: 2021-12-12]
revisions/dimension-charts/outer-dimension-board-x.png

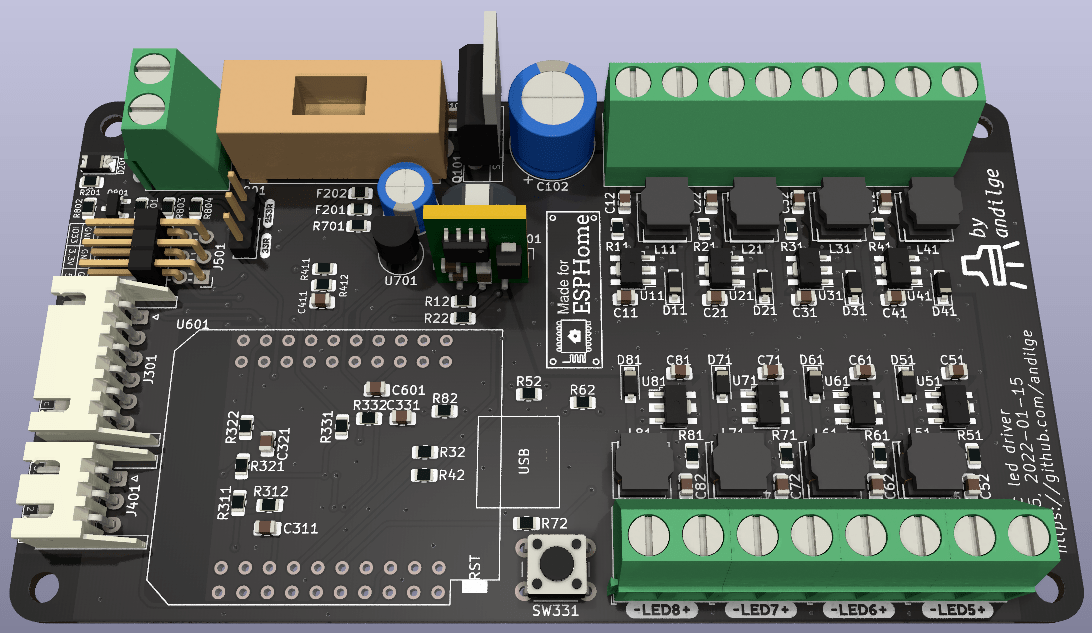
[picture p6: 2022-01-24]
revisions/2022-01-15/board-views/right.png

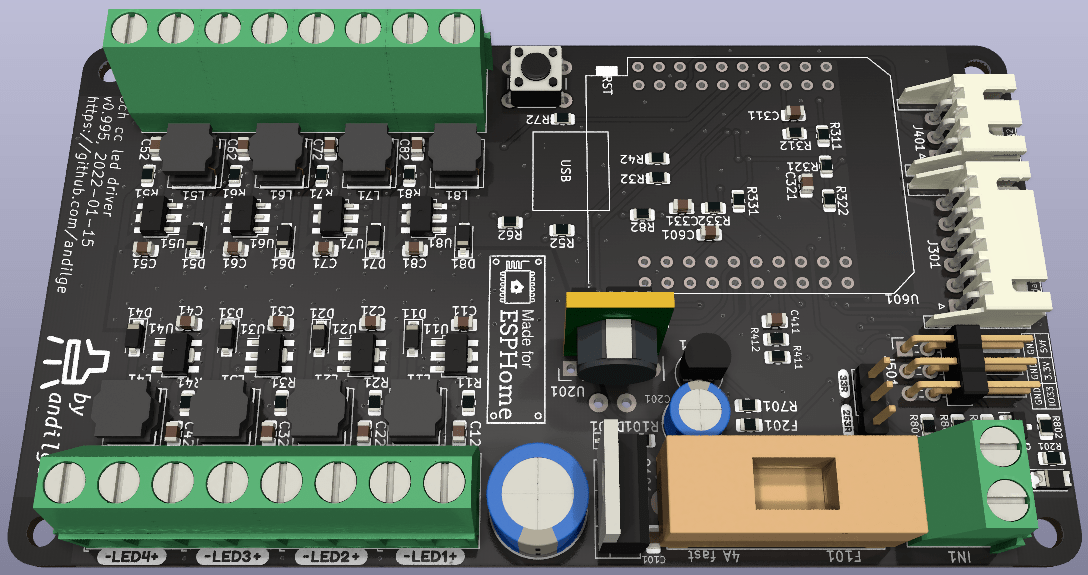
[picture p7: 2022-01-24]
revisions/2022-01-15/board-views/left.png

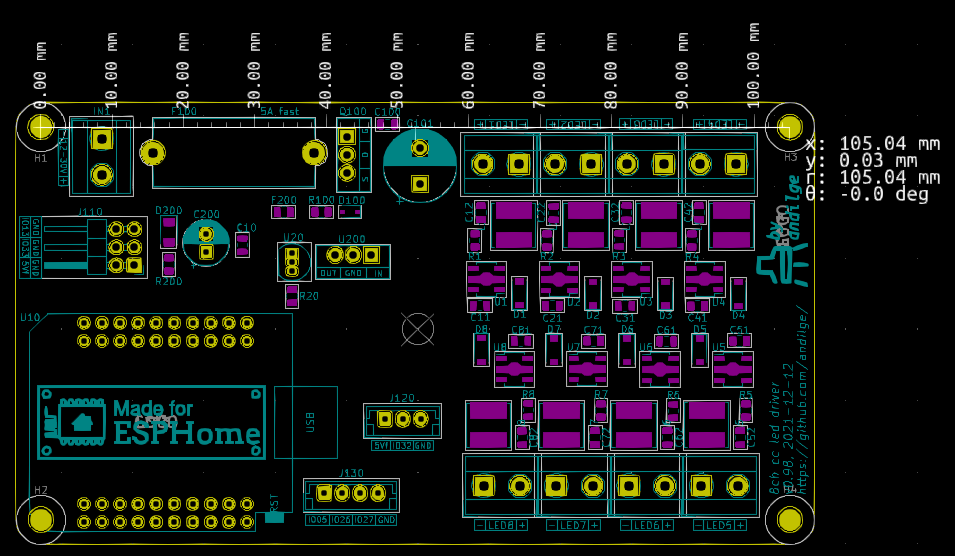
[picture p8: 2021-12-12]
revisions/dimension-charts/mounting-hole-distance-board-x.png

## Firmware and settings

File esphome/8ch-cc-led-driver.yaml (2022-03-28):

---
#########################################
# 8 channel led driver constant current #
#########################################

# code prepared for board v0.996, 2022-02-03

# esp board model:  MH-ET LIVE ESP32 MiniKit

# Pinout reference
# ================
# # --------------------------------------------
# | GPIO | Board | Usage                       |
# |------|-------|-----------------------------|
# | 02   | ~     | blue LED on ESP32 module    |
# |------|-------|-----------------------------|
# | 04   | U701  | dallas temp. sensor         |
# |------|-------|-----------------------------|
# | 05   | J301  | momentary switch            |
# |------|-------|-----------------------------|
# | 13   | J501	 | data out for adressable LED |
# |------|-------|-----------------------------|
# | 16   | LED1	 | LED1 dimming (pwm)          |
# |------|-------|-----------------------------|
# | 17   | LED2	 | LED2 dimming (pwm)          |
# |------|-------|-----------------------------|
# | 18   | LED3	 | LED3 dimming (pwm)          |
# |------|-------|-----------------------------|
# | 19   | LED4	 | LED4 dimming (pwm)          |
# |------|-------|-----------------------------|
# | 21   | LED5  | LED5 dimming (pwm)          |
# |------|-------|-----------------------------|
# | 22   | LED6	 | LED6 dimming (pwm)          |
# |------|-------|-----------------------------|
# | 23   | LED7  | LED7 dimming (pwm)          |
# |------|-------|-----------------------------|
# | 25   | LED8  | LED8 dimming (pwm)          |
# |------|-------|-----------------------------|
# | 26   | J301  | rotary encoder pin A        |
# |------|-------|-----------------------------|
# | 27   | J301  | rotary encoder pin B        |
# |------|-------|-----------------------------|
# | 32   | J401  | motion sensor (pir)         |
# |------|-------|-----------------------------|
# | 33   | J501  | free to use GPIO            |
# ----------------------------------------------

##### basic configs #####

# set up variables
substitutions:
  name: 'Eight Downlights'
  project_name: "andilge.eight-downlights"
  device: 'eight_downlights'
  reboot_timeout: '30min'
  project_version: '0.996'
  pwm_frequency: '19531Hz'
  default_transition: '2.5s'
  gamma_correct: '2.4'
  latitude: '47.348942' # change to your location, find it with https://www.latlong.net/
  longitude: '8.545489' # change to your location, find it with https://www.latlong.net/

# define core configs
esphome:
  name: ${device}
  name_add_mac_suffix: true
  comment: ${name}
  platform: ESP32
  board: mhetesp32minikit
  project:
    name: ${project_name}
    version: "${project_version}"

api:
  reboot_timeout: ${reboot_timeout}

ota:
  safe_mode: true

logger:
  baud_rate: 0 # disable logging to serial

web_server:
  port: 80

wifi:
  ap: {} # This spawns an AP with the device name and mac address with no password.

captive_portal:

# Sets up Bluetooth LE to allow the user to
# provision wifi credentials to the device.
esp32_improv:
  authorizer: none

dashboard_import:
  package_import_url: github://andilge/8ch-constant-current-LED-driver/esphome/8ch-cc-led-driver.yaml

time:
  - platform: homeassistant
    id: homeassistant_time

dallas:
  - pin: GPIO04
    update_interval: 72s # reads out 50/hour, 1200/day

##### start specific configs #####


binary_sensor:
  # define the momentary switch and it's action
  - platform: gpio
    name: '${name} light switch'
    pin:
      number: GPIO05
      mode: 
        input: true
        pullup: false
    filters:
      - invert:
    disabled_by_default: true
    on_multi_click:
      - timing:
          - ON for at most 1s
          - OFF for at least 0.2s
        then:
          - light.toggle: downlight_01
          - light.toggle: downlight_02
          - light.toggle: downlight_03
          - light.toggle: downlight_04
          - light.toggle: downlight_05
          - light.toggle: downlight_06
          - light.toggle: downlight_07
          - light.toggle: downlight_08
      - timing:
          - ON for at least 4s
        then:
          - switch.toggle: auto_night_light

  - platform: gpio
    device_class: motion
    name: '${name} motion'
    id: motion
    pin:
      number: GPIO32
      mode: 
        input: true
        pullup: false
    filters:
      - invert:
    # do night light sequence on motion detection only if switch night light is on
    on_press:
      if:
        condition:
          switch.is_on: night_light
        then:
          script.execute: motion_light_sequence

  - platform: status
    name: '${name} connection'

button:
  - platform: restart
    device_class: restart
    name: '${name} reboot'
    id: restart_button
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

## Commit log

2021-12-10 init big sync
    [BOM.xlsx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]
2021-12-10 add /gerber+drill/imgs directotry to -gitignore
2021-12-10 improoving .gitignore and folder/file structure in gerber + drill directory
2021-12-10 remove some files, moving others in gerber + drill folder
    [BOM.xlsx]
2021-12-11 correcting typo and adjusting min brightness for dial encoder in yaml
    [8ch-cc-led-driver.yaml]
2021-12-11 introducing standardized changelog, usingf 1 changelog at centralized place
    [CC dimmer low voltage-B_Cu.gbl, CC dimmer low voltage-B_Mask.gbs, CC dimmer low voltage-B_Paste.gbp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]
2021-12-11 change hint to buy esp32 and step down converter from aliexpress in CHANGELOG.md
2021-12-11 adding bom.pfs files
    [bom.xlsx]
2021-12-11 removing bom.xlsx wich enterd even with .xlsx in gitignore .. wtf???
    [bom.xlsx]
2021-12-12 fixing errors in bom.pdf
2021-12-12 fixing bom.pdf, adding better footring L1-L8, rotating silkscreen LED1-LED4
2021-12-12 adding README.md in folder "gerber + drill"
2021-12-12 brushing up README.md in folder "gerber + drill"
2021-12-12 brushing up README.md in folder "gerber + drill" 2
2021-12-12 brushing up README.md in folder "gerber + drill" 3
2021-12-12 adding v0.98, new imgs for board dimensions + hole istances
2021-12-12 removing typo in bom.pdf
2021-12-13 brushing up gerbers, added more vias
2021-12-14 removed plan for connector panel board in CHANGELOG.md
2021-12-14 swaping place of power led and capacitor
2021-12-15 adding wtflp license logo on board
2021-12-16 refining .gitignore
    [jlcpcb-bom.csv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]
2021-12-16 introducing bom+cpl for board assembly by jlcpcb
2021-12-16 alternative parts on jlcpcb BOM afer testing assembly
    [jlcpcb-bom.csv]
2021-12-16 brushing up README.md in folder gerber + drills 2
2021-12-16 deleting lines with false content in jlcpcb-bom.csv
    [jlcpcb-bom.csv]
2021-12-16 making things better with jlcpcb bom regagring to "SMD only". Brushing up CHANGELOG.md + README.md
    [jlcpcb-smd-bom.csv]
2021-12-17 revamping naming and structure in revision folder
    [CC dimmer low voltage-B_Cu.gbl, CC dimmer low voltage-B_Mask.gbs, CC dimmer low voltage-B_Paste.gbp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]
2021-12-17 brushin up README.md + updating .gitignore
    [smd-bom.csv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]
2021-12-17 brushing up README.md + minor change in bom.pdf
2021-12-17 brushing up bom.pdf
2021-12-23 adding v0.991
    [bom.ods, smd-bom.csv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]
2021-12-23 correcting file name
    [top-pos.csv]
2021-12-23 brushing up smd bom content
    [smd-bom.csv]
2021-12-25 various brush ups related to v0.991
    [bom.ods, smd-bom.csv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]
2021-12-25 adding board views picture
2021-12-25 brushing up little errors in esphome yaml
    [8ch-cc-led-driver.yaml]
2021-12-26 adding missing LCSC part # in smd-bom.csv
    [smd-bom.csv]
2021-12-27 eliminsting errors in the bom.pdf
    [smd-bom.csv]
2021-12-28 adding netlist and highlight 1st pin to ibom.html
2022-01-05 removing wrong files
    [CC dimmer low voltage.csv]
2022-01-08 actualizing gerber+drill files
2022-01-10 adding gerber+drill files to v0.994
2022-01-24 3d model for buck converter, small track changes
2022-01-24 excluding *.csv from .gitignore
    [smt.bom.csv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]
2022-02-03 completing files for v0.996
    [smt-top-pos.csv]
2022-02-04 adding orientation silkscreen to PT4115
2022-02-04 adding more tools on bom.pdf
2022-02-07 minor updates in footprints, brushing up smt.bom.csv
    [CC dimmer low voltage-B_Cu.gbl, CC dimmer low voltage-B_Mask.gbs, CC dimmer low voltage-B_Paste.gbp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]
2022-02-07 fixing version conflict in folder pcbway-board-fabrication
    [CC dimmer low voltage-B_Cu.gbl, CC dimmer low voltage-B_Mask.gbs, CC dimmer low voltage-B_Paste.gbp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]
2022-02-27 small cosmetic improvments, fixing latest smt position file
    [smt-top-pos.csv]
2022-03-06 minor imprvments in tracking, new gerber+drill files
    [smt.bom.csv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]
2022-03-06 board views with real pictures
2022-03-28 v0.997, improoving tracks and components
    [smt.bom.csv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]
